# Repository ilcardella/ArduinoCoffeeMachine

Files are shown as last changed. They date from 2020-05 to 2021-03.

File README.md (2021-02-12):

# Arduino Coffee Machine 

This project is a PID controller for a `Gaggia Paros` (or Gaggia Classic) coffee machine using Arduino and a few other components.
This Arduino based controller improves the stability of the water temperature of the coffee machine by controlling the boiler with a PID control loop feedback.

## Software

This project is based on [lib_coffee_machine](https://github.com/ilcardella/lib_coffee_machine) which is a C++ library providing an abstraction of a generic coffee machine.

This project implements the library interfaces targeting an Arduino Nano platform and several sensors and displays.

### Arduino libraries

This project depends on the following Arduino libraries:
- [PID](https://github.com/br3ttb/Arduino-PID-Library)
- [TSIC](https://github.com/Schm1tz1/arduino-tsic)
- [SDD1306Ascii](https://github.com/greiman/SSD1306Ascii)
- [MAX6675](https://github.com/adafruit/MAX6675-library)

### Makefile

The `Makefile` at the project root directory provides targets to build the code and the documentation.

### Build

You can build the code with different approaches:
- with the Arduino IDE opening the `CoffeeMachine.ino` sketch
- with VSCode and the [Arduino extension](https://marketplace.visualstudio.com/items?itemName=vsciot-vscode.vscode-arduino) opening the `CoffeeMachine.ino` sketch
- with `make build` using Docker

#### Build with Docker

The code can be built inside a Docker container using docker-compose. The `docker-compose.yml` and the `Dockerfile` are in the `docker` directory. The `docker-compose.yml` depends on 2 environment variables that must be defined before starting the build:
- CORE: the Arduino core
- BOARD: the Arduino board to use

Refer to the [arduino-cli](https://arduino.github.io/arduino-cli/) documentation for the list of available cores and boards.
The following is an example that builds the code for an Arduino Nano board:

```
$ cd /path/to/repo
$ CORE=avr BOARD=nano make build
```

The generated build files will be in the `CoffeeMachine/build` directory.

After building the Docker image the first time, you can then use the `arduino-cli` installed in the Docker image directly with:

```
$ cd /path/to/repo
$ docker run --rm -it -v $PWD:/build arduino-builder arduino-cli version
arduino-cli Version: 0.10.0 Commit: ec5c3ed
```

## Hardware

### Components

This is the list of components I used for the project:
- 1x Arduino Nano (any board type will do)
- 1x Solid State Relay 40A
- 2x Digital temperature sensors (e.g. TSic306)
- 1x I2C 128x64 OLED
- Wires and other supplies

## Documentation

Read the project documentation at: https://arduinocoffeemachine.readthedocs.io

Or build it locally with:

```
$ cd /path/to/repo
$ make docs
```

## Tools

The `tools` directory contains a Python script that can be used to read the Arduino
Serial messages and to plot the current water temperature on a graph. The goal
is to help the PID tuning process showing the realtime results.

```
$ cd tools
$ poetry install --no-dev
$ poetry run python temp_plotter.py
```

## Acknowledgement

A big thanks goes to these two other projects that helped me a lot in the understanding of the electric schematics of the coffee machine and the components to use:
- [RaspberryPI based](http://int03.co.uk/blog/project-coffee-espiresso-machine/)
- [Arduino based](http://www.cyberelectronics.org/?p=458)

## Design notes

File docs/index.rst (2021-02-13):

Arduino Coffee Machine's documentation
######################################

.. important:: This project is a work in progress, I will update the documentation while
   I progress with the work and things might change along the road

Introduction
************

This project is a modification for Gaggia coffee machines replacing the
existing thermostats with a PID controller powered by Arduino.
This modification could be applied to other machines too, but
in this document I will describe how I modified a ``Gaggia Paros``.
The ``Gaggia Paros`` is almost identical in its parts to a ``Gaggia Classic`` and it comes
combined with a coffee grinder.

To add a PID controller to the coffee machine we'll need to replace the existing
thermostats that control the heater. There are 2 thermostats to allow the operation
of the machine heating water to brew temperature and also steam temperature.
Unfortunately these thermostats do not allow a fine control of the water temperature,
being a simple on/off switch without any logic behind.
The result is that they don't keep the water/steam temperature stable enough to allow
consistency of the brewed coffee.

.. toctree::
   :maxdepth: 1
   :numbered:
   :caption: Documentation

   src/documentation

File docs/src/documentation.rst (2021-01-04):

Overview
********

This is the electric diagram of the ``Gaggia Paros``:

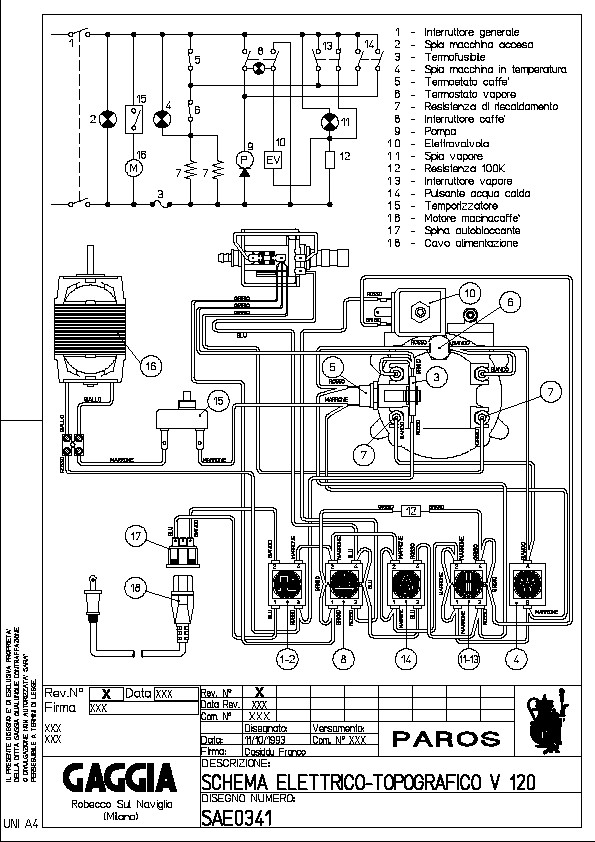
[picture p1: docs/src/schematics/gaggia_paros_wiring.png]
Gaggia Paros electrical wiring


    Gaggia Paros electrical wiring

The switches ``5`` and ``6`` represent the two thermostats that are going to be replaced
with two temperature sensors and a Solid State Relay that the Arduino will
use to control the heater.
The second required modification is to connect the Arduino to the left pins of the
"double switch" number ``13``. This will allow the Arduino to know if the Steam button
has been pressed in order to target the correct temperature.

This is the list of materials I used for this project. The purpose here is to just give
an idea of what I used, you can change anything as you might prefer:

* Temperature sensors (x2). I tried with both:
    * TSic 306 digital temperature sensor
    * K-type thermocouple with a MAX6675 ADC module
* 128x64 OLED with SSD1306 controller
* Arduino Nano
* Arduino Nano expansion connection shield
* Fotek clone SSR 40A
* Wires 22AWG (low voltage) and 18AWG (AC line)
* Heat shrinking sleeves
* T-tap (scotch) connectors
* Thermal paste
* M4 brass hexagonal standoff

This is the diagram of all the components connected for testing on a breadboard.
In the diagram the thermocouple sensors are missing and their pins are to be considered
as connected to the two MAX6675 modules.
The same exception is true for the SSR AC pins.

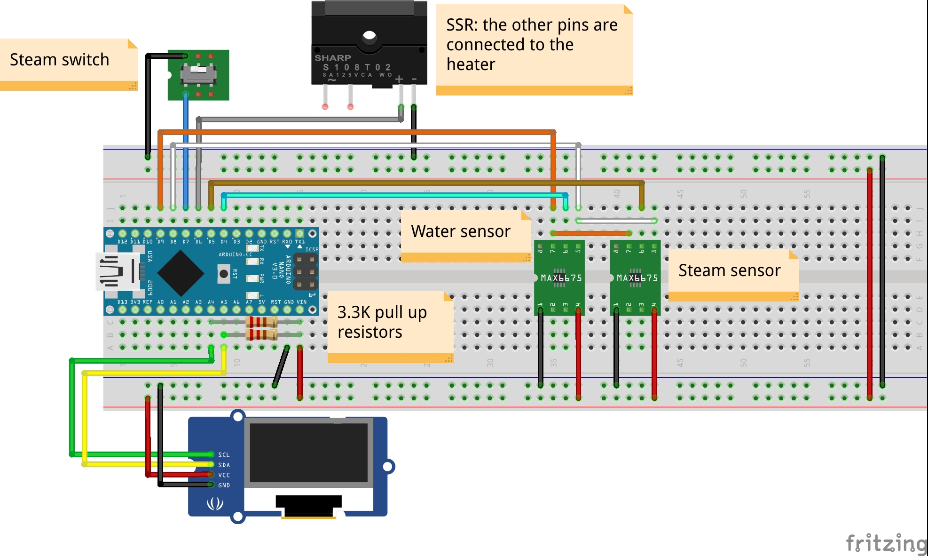
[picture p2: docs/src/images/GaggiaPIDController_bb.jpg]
Breadboard circuit diagram


    Breadboard circuit diagram

Arduino
*******

I decided to use an Arduino Nano because of its small size and the USB port which
is handy to upload sketches and interface with the Serial for debugging.
I decided to not use a PCB as most of the components are far from each other and I wanted
to allow easy plug and play of each module.
I then connected the Arduino Nano to an expansion board that allows to connect wires
with screw connectors without having to solder anything.
I 3D printed a simple box to contain and isolate the Arduino from the machine frame.

Arduino Nano and its expansion board

    Arduino Nano and its expansion board

Temperature sensors
*******************

I have tested this whole setup with two different types of sensors:

* TSic306
* K-type thermocouple

TSic306
=======

At first I decided to use the TSic 306 digital temperature sensors. As suggested
in similar projects there are several benefits: it's digital so no need for ADC or
external bridge boards, max operational temperature is +150deg C which is ok as the
steam needs to get around 145deg C and it comes in a TO92 package which is quite compact.

The main challenge I had with these sensors was fitting them in the heater: the
stock thermostats are connected through a M4 screw, so following advice from other
similar projects I bought a couple of brass hexagonal standoff with a M4 male thread and
I tried to find a way to assemply the sensors into them.

Unfortunately the TO92 package is 4.5mm wide so I used some sand paper to smooth the
corners of the sensors, trying to not damage the internal wirings. Ideally I would
have drilled the M4 female thread but I did not have a drill at hand :(

I then filled the female thread with thermal paste and I inserted the sensors in the
paste. Eventually I covered everything with a heat shrinking sleeve.

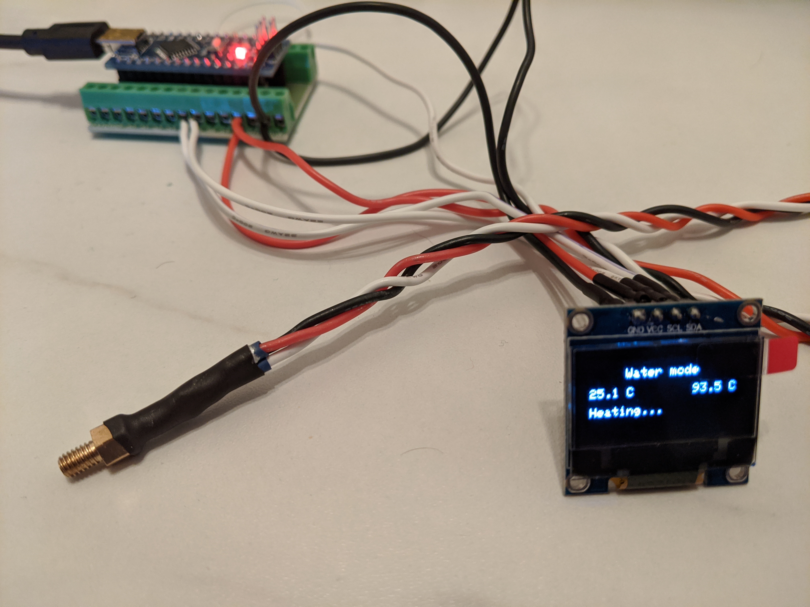
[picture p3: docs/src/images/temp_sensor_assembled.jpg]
Temperature sensor TSic306 assembled


    Temperature sensor TSic306 assembled

This setup worked very well for several months until I had to do some maintenance to the
machine: removing the heater to replace the solenoid valve I broke one of them.
The problem with this solution was that the two sensors were not really stable
in the brass standoff and it was easy to knock them off by touching them or pulling the
wires.

K-type thermocouple
===================

I then decided to try out two K-type thermocouples. I bought two of those that
come already assembled on an M4 nut (designed for 3D printers) which is handy as this was
the weak point of the previous solution.

The main drawback is that they require a voltage amplifier and an ADC to digitalise the
signal.
Fortunately both of these can be sourced in a single package, the MAX6675 module.
The Arduino can "speak" with the MAX6675 with the SPI protocol requiring 2 more pins
compared to the digital sensor solution. Not a big deal as there are plenty available.

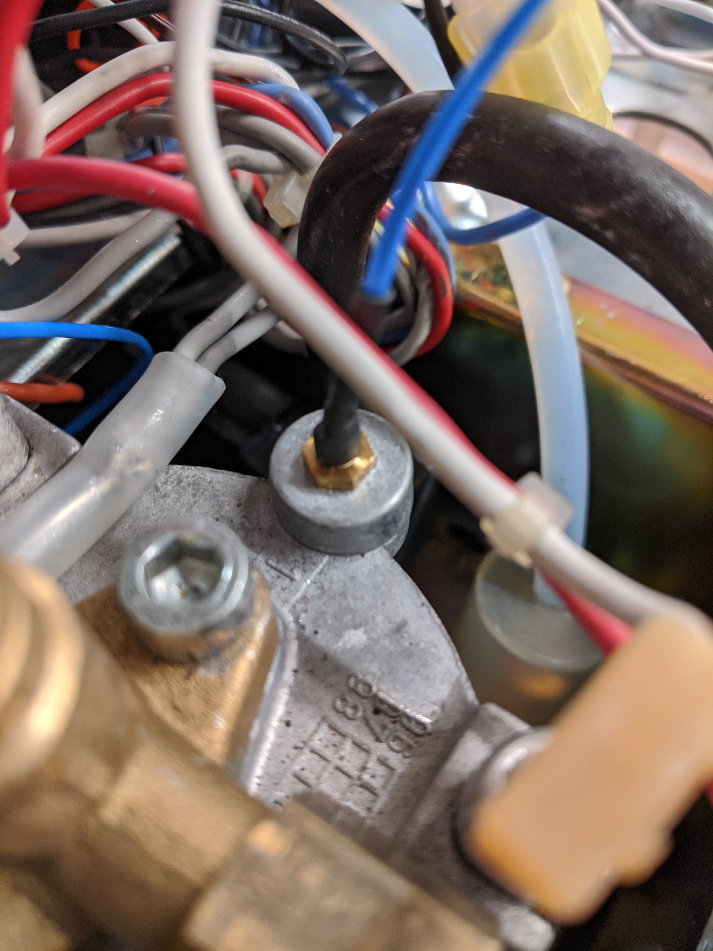
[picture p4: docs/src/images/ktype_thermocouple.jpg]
K-type thermocouples assembled on the heater


    K-type thermocouples assembled on the heater

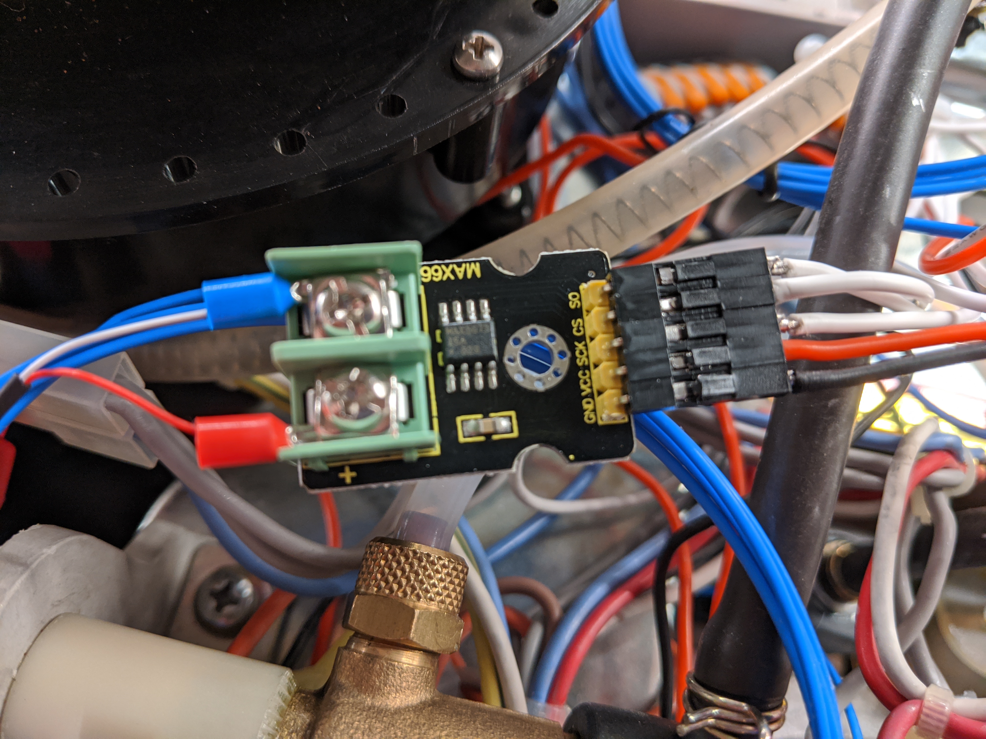
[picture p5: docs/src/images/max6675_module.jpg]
MAX6675 module


    MAX6675 module

Another possible drawback with thermocouple is the error they might be subject to:
again I was not really worried about this because even if there is a ~2deg C error, as
long as it's stable (basically just an offset) it would not impact the PID performances.

Solid State Relay
*****************

I used one of the common (and cheap) Fotek clone SSR. From what I could read online
these clones usually contain underrated triac, so to stay on the safe side I used the
40A version with the hope it's not going to blow up.
This type of SSR can be controlled with a signal in the range 3-32 VDC and they update
the output when the AC signal crosses its zero level.

The SSR can be placed inside the coffee machine with it's metal back side on the coffee
machine metal frame in order to dissipate any heat. The control signals are going to be
wired to the Arduino board: one to ``GND`` and one to the selected digital pin.

Arduino Nano and the Fotek SSR

    Arduino Nano and the Fotek SSR

The AC terminals instead needs to be connected to replace the two thermostats. One
themostat is connected to a ``red`` and a ``brown`` wire, while the second one is
connected to a ``white`` and again a ``red`` wire. I connected the SSR terminals using
a piece of 18AWG wire and 2 male spade connectors, one to the ``brown`` connector
of the first thermostat and the second one to the ``white`` connector of the other
thermostat.

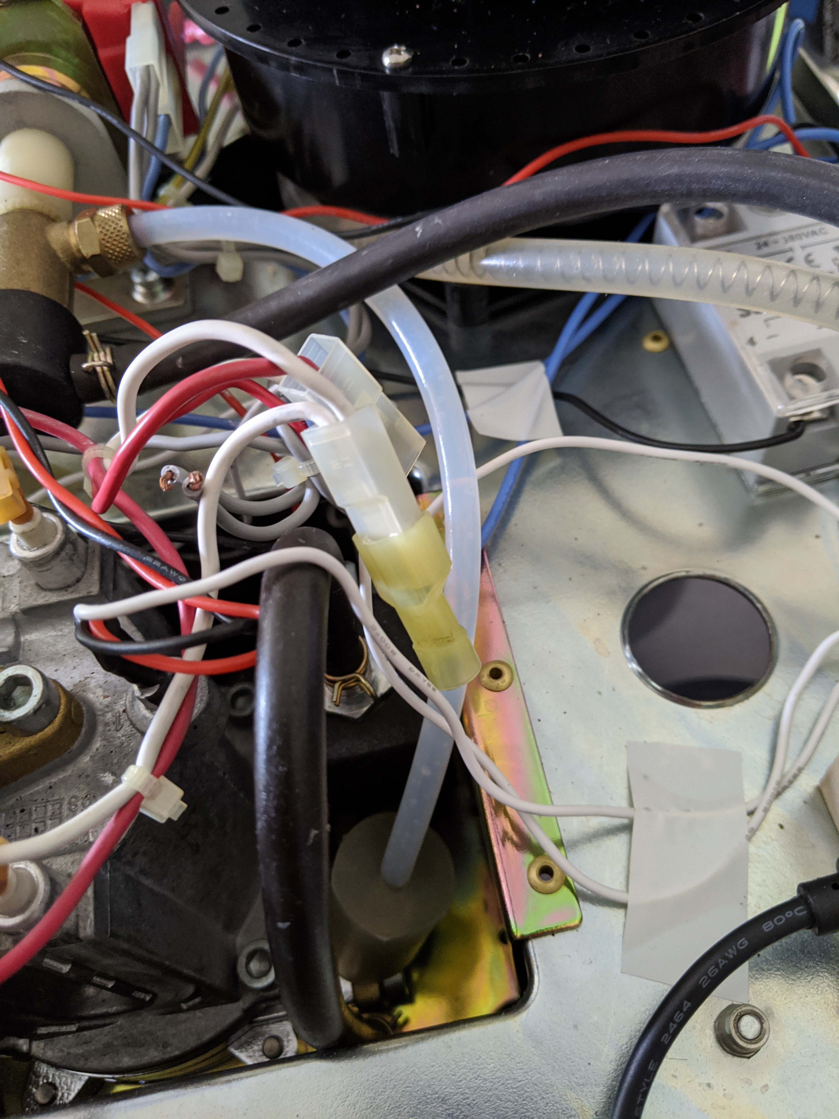
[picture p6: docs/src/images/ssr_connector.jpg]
Connection between SSR and the heater


    Connection between SSR and the heater

Power supply
************

There might be different ways to power the "low voltage" electronic for this project,
at first I thought to use AAA batteries as the overall consumption is very low and the
whole circuit is on only for 30min a day in average.
Eventually I decided to take power from the main AC source using T-Tap connectors and use
an AC-DC switch converter (cheap from Ebay).

TTap connector on AC power line

    TTap connector on AC power line

Using the T-Tap connectors allowed me to not having to cut or solder almost anything, and
everything can still be removed reverting the machine back to it's original state.

Eventually I enclosed the whole circuit board in 3D printed plastic case leaving it inside
the coffee machine, as far as possible from any other components. The 5V lines has been
wired to reach the Arduino board and the temperature sensors.

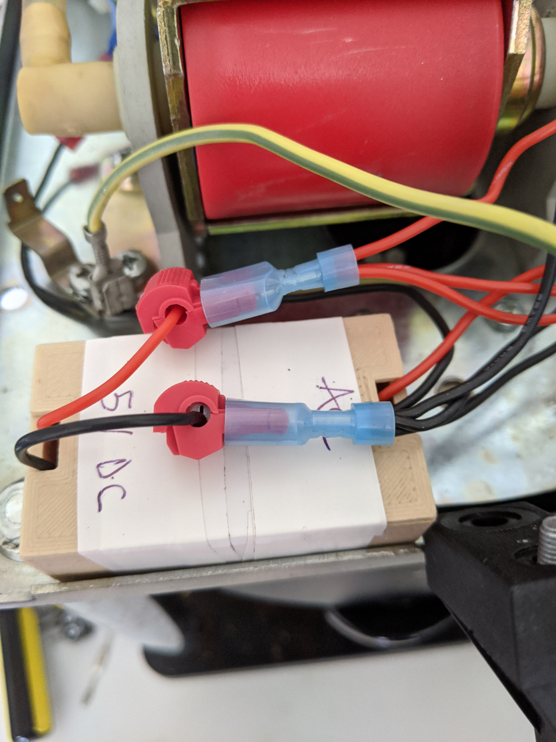
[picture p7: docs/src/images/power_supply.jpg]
Power supply enclosure


    Power supply enclosure

I also used two clamp wire connectors for the ``5V`` and ``GND`` bus, again this makes
it easier and faster to assemble everything and swap components if required.

Clamp wire connectors for 5V and GND

    Clamp wire connectors for 5V and GND

Display
*******

There is not a constraint on what display you can use, in my case I chose an OLED 128x64.
This display uses the ``SSD1306`` controller and you can find several Arduino libraries
that let you interface with it.
The main reason to choose this type of display was that it uses the I2C protocol so I
only needed 2 Arduino pins to control it (plus 2 to power it up).

Steam button
************

To detect the machine operation mode, the Arduino needs to be connected to the machine
steam mode button. The button has 4 "pins", two by two isolated. It's important to
disconnect the correct two connectors: those that where bypassing the water thermostat
in order to use the steam thermostat which has a higher trigger temperature. The other
two connectors are important because the control the solenoid valve.
Use the circuit diagram to clarify any doubt.

One of the two pins has to be connected to ``GND``, while the second goes to the
selected Arduino input digital pin, which must be set to ``INPUT_PULLUP`` mode.

Assembly
********

In this section I'll recap the steps I took from the beginning, until the final
assembly with the PID controller installed in the coffee machine.

Once gathered all the materials for initial testing I wired everything on a breadboard
to verify that the code was working as expected:

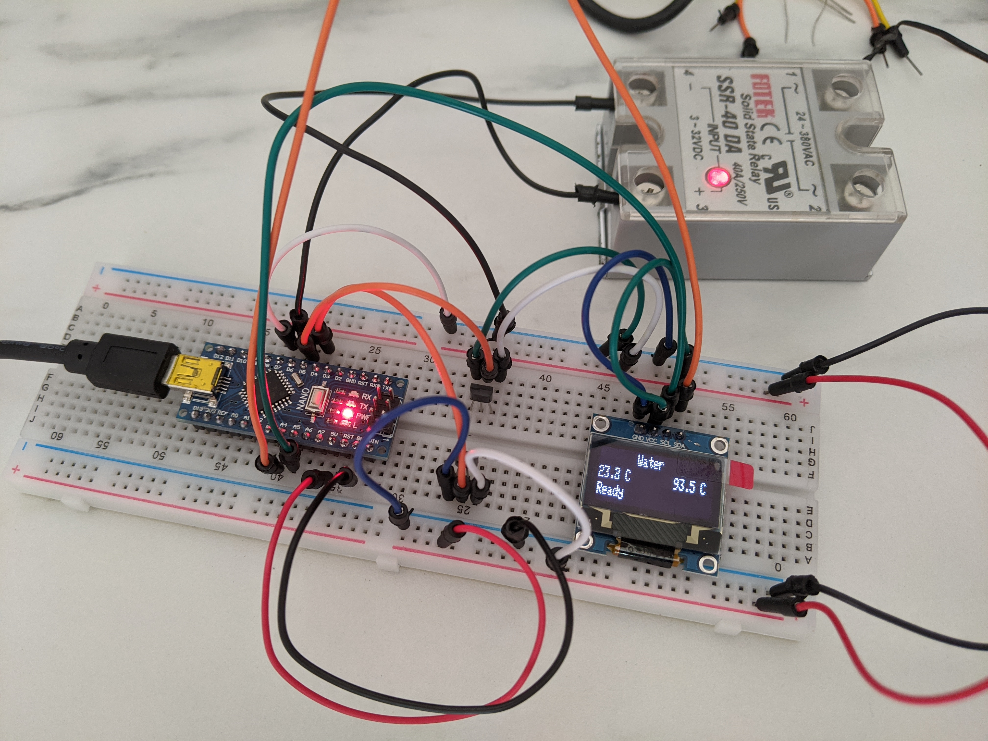
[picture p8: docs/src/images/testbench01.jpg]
Testbench assembly


    Testbench assembly

This also helped me to find a good starting point for the PID gains, at least better than
leaving them set to ``1``. They have been tuned again once everything was connected to the
machine heater.

First I applied two T-Tap connectors to the main AC power line. one can be applied
to the Neutral just after the input socket, but it's important to connect the second one
**after** the main power button. This allows the Arduino to turn on only when the machine
is on.

The AC-DC converter can be placed into it's plastic container and the AC terminals can
be connected to the two T-Tap connectors. The 5V output is going to be connected to the
Arduino, the sensors and the display.

I then assembled the temperature sensors by unscrewing the thermostats and replacing
them with the two sensors. For the water sensor, the heater must be freed removing its 4
screws that keeps it connected to the main group.

I placed the Arduino Nano with the expansion board and a plastic enclosure in the only
available space on the machine frame and I wired the 5V into the ``Vin`` pin, the ``GND``
and the temperature sensors signal wires.

I then positioned the SSR near the coffee grinder, connecting it's DC terminals to ``GND``
and to the Arduino pin, for the AC terminals instead I used 18 AWG wire with male
spade connectors, that have been connected as described in `Solid State Relay`_.

I removed the two connectors from the steam mode button which where used to short circuit
one of the thermostat. I used two T-Tap connectors as "female" spade connectors and I
wired them to ``GND`` and the Arduino pin.

Regarding the display, I decided to place it on the front of the machine, between
the amin group and the grinder, where there is a small unused gap. I wired the I2C
signals from the Arduino to the front of the machine and together if ``5V`` and ``GND``
from the power supply, I placed everything at the front of the machine.

Eventually I checked I connected all the wires to the appropriate port in the Arduino
expansion shield and then I placed the external enclosure on the coffee machine back.

This is how the ``Gaggia Paros`` looks like after the modification.
The inside:

Final internal assembly of the Gaggia Paros

    Final internal assembly of the Gaggia Paros

And the outside:

Final external assembly of the Gaggia Paros

    Final external assembly of the Gaggia Paros

PID Tuning
**********

The last step was improving the PID controller by tuning the gains in order to achieve
the best possible control of the heater.
There are several guides online that explain what each gain does and how to resolve
specific issues, I am not expert so I won't cover this part. My suggestion is to get a
basic understanding of how a PID controller works and then just try changing the gain
values to see the effect.

The Arduino code is configured by default to send the current machine status to the Serial
Interface in a comma separated string format.
In the repository ``tools`` directory there is a Python script that connects to
the machine serial port ``/dev/ttyUSB0`` (a different port can be specified), reading
these messages coming from the Arduino and plotting the water temperature on a graph.

Having a real-time plot of the water temperature will help massively the PID tuning
process, because you will clearly see the oscillations or the overshooting and it will
be easier to correct them.

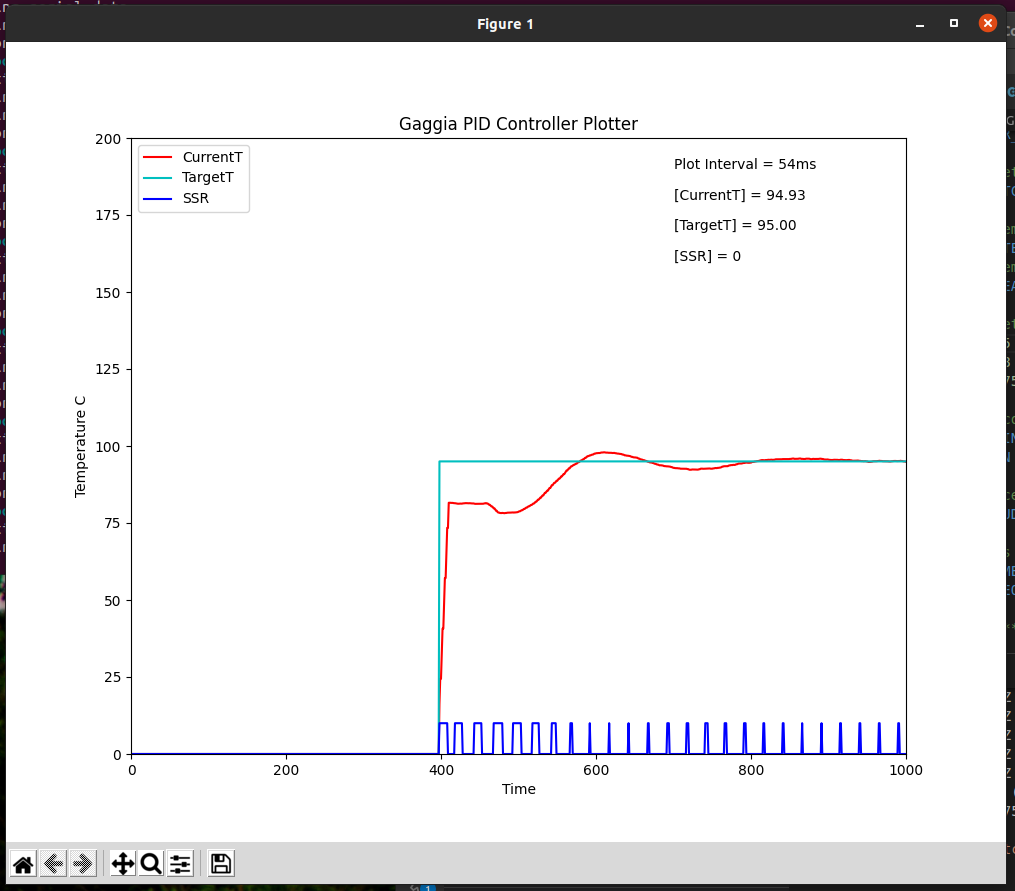
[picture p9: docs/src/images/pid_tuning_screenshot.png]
PID tuning temperature plot


    PID tuning temperature plot

Improvements
************

After a few months of use, everything still seems to be working as expected. The coffee
quality has certainly improved and it's more consistent than before, I really advise
to apply such modification to any coffee machine!

There are still a few things that I'd like to improve:

- Improve the internal wiring, I did not do a good job on that front
- Replace the Arduino Nano with a ESP8266 based board to have WiFi connectivity

I hope these notes are useful to anybody attempting a similar modification and please
submit Issues or PR on the GitHub repository.

Enjoy the coffee!

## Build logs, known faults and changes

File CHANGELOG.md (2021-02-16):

# Arduino Coffee Machine Changelog

All notable changes to this project will be documented in this file.

The format is based on [Keep a Changelog](https://keepachangelog.com/en/1.0.0/),
and this project adheres to [Semantic Versioning](https://semver.org/spec/v2.0.0.html).

## []
### Changed
- Updated version of `lib-coffee-machine` and include paths

## [2.0.0] - 13/02/2020
### Added
- Thermocouple sensor support a temperature offset to account for static error
- Wrapper for all Arduino.h functions and types
- CMake configuration for non-Arduino dependant code
- Automated test suite for non-Arduino dependant codebase
- Circuit diagram in documentation

### Changed
- Reformat of the `TemperatureSensor` class using template for sensor implementation
- Replaced use of Arduino String with char array
- Configuration for coffee_machine library is provided through a template argument
- Use `lib-coffee-machine` external library for core functionalities

### Fixed
- Resolved crash due to String assignments
- Fixed print formatting of float and double
- Fixed bug in MovingAverage affected by the creation of an instance with 0 history length

## [1.1.0] - 2020-08-22
### Added
- Added python script to plot machine temperatures reported through serial interface
- Configurable safety timeouts to turn the heater off after a set period of time
- Added support for K-type thermocouple sensors with MAX6675 and SPI interface

### Changed
- Display shows status of the machine indicating if it's heating, cooling or ready for brew
- Performed PID tuning to reduce oscillation of temperature
- Updated steam switch mode to use internal pullup resistor

## [1.0.0] - 2020-05-03
### Added
- First release:
  - Support for TSic306 digital temperature sensor
  - SSR control with PID loop
  - Support for SSD1306 OLED 128x64 display
  - Serial interface to show debug information

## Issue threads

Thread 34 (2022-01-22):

First Project

nkabbara, 2022-01-22:
Wow! Thanks for such a great tutorial. I'm planning to do the same for my Gaggia Classic Pro.

Question, I don't have much experience with arduino and electronics. I'm a software guy. This feels like too big of a project to start with.

What's in your opinion some other smaller projects (could be unrelated) to do in order to build some experience before jumping into this?

ilcardella, 2022-01-24:
Hi, thanks for the feedback. I think if you want to start experimenting with electronics and Arduino the easiest would be to start from their official website documentation. https://www.arduino.cc/
They have a lot of tutorials and projects ideas from basics to more advanced. This will give you some basics on electronics and how thing works. Also the forum contains a lot of useful discussions.My advice is to choose a project around something you are passionate about so that it would motivate you in finishing it. For example, you like gardening then there are several project around monitoring plants, automating watering etc. If you like robotics you can find dozens of kits to assemble and code...

Closed 2022-02-14.

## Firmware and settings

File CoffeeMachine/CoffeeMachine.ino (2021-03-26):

#include "libraries/arduino_adapter.h"
#include "libraries/arduino_pin.h"
#include "libraries/configuration.h"
#include "libraries/factories.h"

#include "libraries/lib_coffee_machine/include/lib_coffee_machine/coffee_machine.h"

using Adapter = ArduinoAdapter;

CoffeeMachine<Adapter, Configuration> *machine;

void setup()
{
    auto display = DisplayFactory::make_display<Configuration>();
    auto serial = SerialFactory::make_serial_interface<Configuration>();
    auto controller = ControllerFactory::make_controller<Configuration>();
    auto mode_swith_pin = new ArduinoPin(Configuration::STEAM_SWITCH_PIN);
    auto heater_pin = new ArduinoPin(Configuration::HEATER_SSR_PIN);
    auto water_sensor = SensorFactory::make_water_temperature_sensor<Configuration>();
    auto steam_sensor = SensorFactory::make_steam_temperature_sensor<Configuration>();

    machine = new CoffeeMachine<Adapter, Configuration>(
        controller, serial, mode_swith_pin, display, heater_pin, water_sensor,
        steam_sensor);

    // Allow sensors to initialise
    delay(500);
}

void loop()
{
    if (machine)
    {
        machine->spin();
        delay(1);
    }
    else
    {
        Serial.println("Error initialising coffee machine");
        delay(1000);
    }
}

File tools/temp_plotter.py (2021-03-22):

#!/usr/bin/env python3

from threading import Thread
import serial
import time
import matplotlib.pyplot as plt
import matplotlib.animation as animation
import copy
import argparse


class SerialPlotter:
    def __init__(self, port, baudrate, plot_size=1000):
        print("Starting serial connection...")
        self.plot_size = plot_size
        # Serial connection
        self.connection = serial.Serial(port, baudrate)
        # Read serial data in the background
        self.data_reader = Thread(target=self.read_serial_data)
        # Notify input data started
        self.receiving_data = False
        # Flag to stop the endless background thread
        self.active = True
        # Serial raw bytes
        self.raw_data = bytes()
        # List to store data to plot
        self.data = {
            "current": [0 for i in range(self.plot_size)],
            "target": [0 for i in range(self.plot_size)],
            "ssr": [0 for i in range(self.plot_size)],
        }
        self.previous_plot_timer = 0

    def start(self):
        print("Reading serial data...")
        # self.send("output on")
        self.data_reader.start()
        while not self.receiving_data:
            time.sleep(0.1)
        self.setup_plot()
        plt.show()

    def stop(self):
        print("Disconnecting serial connection...")
        # self.send("output off")
        self.active = False
        self.data_reader.join()
        self.connection.close()

    def setup_plot(self):
        fig = plt.figure(figsize=(10, 8))
        ax = plt.axes(xlim=(0.0, self.plot_size), ylim=(0.0, 200.0))
        ax.set_title("Temperature Plotter")
        ax.set_xlabel("Time")
        ax.set_ylabel("Temperature C")

        line_labels = ["CurrentT", "TargetT", "SSR"]
        styles = ["r-", "c-", "b-"]
        x_ax_text = ax.text(0.70, 0.95, "", transform=ax.transAxes)
        lines = []
        lines_text = []
        for i in range(len(self.data)):
            lines.append(ax.plot([], [], styles[i], label=line_labels[i])[0])
            lines_text.append(
                ax.text(0.70, 0.90 - i * 0.05, "", transform=ax.transAxes)
            )
        self.anim = animation.FuncAnimation(
            fig,
            self.decode_and_plot_data,
            fargs=(lines, lines_text, line_labels, x_ax_text),
            interval=50,
        )
        plt.legend(loc="upper left")

    def read_serial_data(self):
        time.sleep(1)
        self.connection.reset_input_buffer()
        while self.active:
            self.raw_data = self.connection.readline()
            self.receiving_data = True

    def decode_and_plot_data(self, frame, lines, lines_text, line_labels, x_ax_text):
        currentTimer = time.perf_counter()
        self.plot_timer = int((currentTimer - self.previous_plot_timer) * 1000)
        self.previous_plot_timer = currentTimer
        x_ax_text.set_text("Plot Interval = " + str(self.plot_timer) + "ms")
        # Update the plot only if new data was received
        if len(self.raw_data) < 1:
            return
        # Decode raw data
        string_data = copy.deepcopy(self.raw_data[:]).decode("utf-8").split(",")
        # Add decoded data into plot datastores
        if len(string_data) < 3:
            return
        self.data["current"].append(float(string_data[1]))
        self.data["target"].append(float(string_data[2]))
        self.data["ssr"].append(int(string_data[3]) * 10)
        # Update plot with decoded data
        lines[0].set_data(
            range(self.plot_size), self.data["current"][-self.plot_size :]
        )
        lines_text[0].set_text("[" + line_labels[0] + "] = " + str(string_data[1]))
        lines[1].set_data(range(self.plot_size), self.data["target"][-self.plot_size :])
        lines_text[1].set_text("[" + line_labels[1] + "] = " + str(string_data[2]))
        lines[2].set_data(range(self.plot_size), self.data["ssr"][-self.plot_size :])
        lines_text[2].set_text("[" + line_labels[2] + "] = " + str(string_data[3]))
        # Reset raw data
        self.raw_data = bytes()

    def send(self, string):
        print("Sending: {}".format(string))
        self.connection.write(bytes(string.encode("utf-8")))


def main():
    parser = argparse.ArgumentParser(prog="Temperature Serial Plotter")
    parser.add_argument(
        "-d",
        "--device",
        help="The full path of the serial device to use",
        default="/dev/ttyUSB0",
        metavar="DEVICE",
        type=str,
    )
    parser.add_argument(
        "-b",
        "--baudrate",
        help="The baudrate used to communicate with the serial device",
        default=9600,
        metavar="BAUDRATE",
        type=int,
    )
    args = parser.parse_args()
    try:
        plotter = SerialPlotter(port=args.device, baudrate=args.baudrate)
        plotter.start()
    except serial.serialutil.SerialException as e:
        print(e)
        exit(1)
    except Exception as e:
        print(e)
    print("Exiting...")
    plotter.stop()


if __name__ == "__main__":
    main()

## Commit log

2020-04-11 Added main loop with PID controller and temperature readings
2020-04-11 Added debug prints
2020-04-12 pid step return output as reference and return value highlights issues
2020-04-16 renamed src folder to project name due to Arduino policy
2020-04-18 fix bug in setting heater ssr pin
2020-04-18 added schematic
2020-04-19 Temperature reads are protected from spikes
2020-04-19 Added pid gains tuning from serial interface and disabled display
2020-05-02 Fixed bug in overflowing of pid wrapper class
2020-05-02 Replaced millis() check in PID wrapper with module check
2020-05-03 PID gains from serials are reset after upadting pid
2020-05-17 Serial plot (#1)
    * Added python script to plot temperatures
    * Updated changelog
2020-05-24 Mode switch fix (#4)
    * Updated PID gains and added ModeDetector class
    * Updated PID gains and added ModeDetector class
2020-05-24 Added assembled sensor picture in documentation
2020-05-25 Performed first PID tuning
2020-05-28 Performed PID gain tuning
2020-07-18 Added safety timeouts to turn off the heater (#5)
    * Added safety timeouts to turn off the heater
    * Updated build script
2020-08-20 Added support for Ktype thermocouple with MAX6675 ADC (#8)
    * Refactored sensor initialisation and created sensor base class
    * Refactored sensor initialisation and created sensor base class
    * Added support for Ktype thermocouple sensors with MAX6675
    * Updated documentation
    * Added moving average to sensor readings
    * created TemperatureSensor base class
    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
2020-08-20 Updated poetry.lock for temperature plotter script
2020-08-22 Made read period configurable per sensor
2020-08-22 PID Tuning - PID gains are double - made moving average configurable per sensor
2020-08-24 Temperature sensor can be configured with a temperature offset for static errors (#9)
2020-09-07 Temperature Sensor class refactor using template (#11)
    * Reformat of TemperatureSensor class using template
    * Reformat of TemperatureSensor class using template
    [Configuration.h]
2020-10-11 Refactored code adding CoffeeMachine main class and dependency injection of sub-components (#12)
    * Refactored codebase to use template classes with an wrapper for Arduino types
    * Replaced arduino types with generic types
    * moved headers in libraries folder and created main wrapper class
    * Created base types and use dependency injection for main class CoffeeMachine
    * corrected type definition
2020-10-14 Added unit test for coffee_machine library and mock components (#13)
    * Added mock components and unit test for coffee_machine library
    * removed files from wrong merge
    * Added unit test for pid controller
    * Added safety timeouts unit test
    * Updated pid controller unit test
    * Added serial interface unit test
    * Updated readme
2020-10-24 Abstracted all subcomponents and included them in the coffee_machine library (#14)
    * Abstracted Display implementation
    * Abstracted PID controller implementation
    * Moved abstract components in coffee machine library
    * Created factories for Display and PID controller
2020-10-30 Replaced use of String with char array (#15)
    * Fixed ArduinoAdapter function namespace and simplified CoffeeMachine library
    * Replaced use of String with char array
2020-11-01 Fixed print formatting of float values (#16)
2021-01-04 added circuit diagram and replaced final mod picture (#17)
    [GaggiaPIDController.fzz]
2021-02-06 Refactor of coffee_machine library and renamed codebase (#20)
    * Refactor of Display@
    * Refactor of SerialInterface
    * Renamed all codebase and refactored interfaces
    * Refactor of TemperatureSensor interface
    * updated test suite with new library design
    * Fixed and cleaned up the unit test
2021-02-11 Rename repository (#23)
    * Renamed codebase removing gaggia references
    * removed wrong submodule
    * Added correct submodule
    [CoffeeMachine.ino, temp_plotter.py]
